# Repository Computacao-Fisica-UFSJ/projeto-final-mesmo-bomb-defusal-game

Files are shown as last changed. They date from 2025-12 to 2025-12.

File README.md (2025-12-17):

# Sistema de Climatização Inteligente via Wi-Fi, com Infravermelho

**Integrantes:**
* Lucas Eduardo Bernardes de Paula
* Messias Feres Curi Melo

## 1. Contextualização do Projeto
Este projeto consiste no desenvolvimento de uma central de automação residencial focada no monitoramento climático e controle de dispositivos via infravermelho (IR). O sistema utiliza um **Arduino Mega** como controlador central, integrando conectividade Wi-Fi para gerenciamento remoto e sensores para leitura ambiental.

O objetivo principal é criar um ecossistema capaz de ler a temperatura e umidade do ambiente e permitir o acionamento remoto de Ar-Condicionados através de uma interface. O projeto explora conceitos de IoT (Internet das Coisas), protocolos de comunicação Serial (UART), manipulação de sinais infravermelhos e servidores Web embarcados.

## 2. Dinâmica e Funcionalidades
O sistema opera executando três tarefas principais simultaneamente:

1. **Monitoramento Climático (DHT22):**
* O sensor lê constantemente a temperatura e a umidade do local.
* Esses dados são exibidos em tempo real na interface Web acessível pelo navegador.

2. **Interface Web e Conectividade (ESP-01):**
* O módulo ESP-01 atua como um servidor Web. Ele gera uma página HTML (estilo "App") que exibe os dados climáticos.

3. **Controle Infravermelho (IR):**
* **Modo de Aprendizado:** O sistema possui um receptor capaz de ler sinais de controles remotos convencionais para "clonar" suas funções.
* **Modo de Envio:** Através de um LED emissor IR, o Arduino replica os códigos salvos para controlar os aparelhos, substituindo o controle físico.

## 3. Lista de Materiais
| Material | Especificação | Quantidade |
| --- | --- | --- |
| **Microcontrolador** | Arduino Mega 2560 | 1 |
| **Módulo Wi-Fi** | ESP8266 (Modelo ESP-01) | 1 |
| **Sensor Climático** | DHT22 (AM2302) | 1 |
| **Receptor IR** | Módulo KY-022 | 1 |
| **Transistor Bipolar** | BC547  | 1 |
| **Emissor IR** | LED Infravermelho (5mm) | 1 |
| **Resistores** | 220Ω e 330Ω (p/ LED) | 2 |
| **Conexões** | Protoboard 400 furos + Jumpers | 1 |

## 4. Diagrama de Montagem
Abaixo está o esquema de ligação dos componentes desenvolvido no software Fritzing.

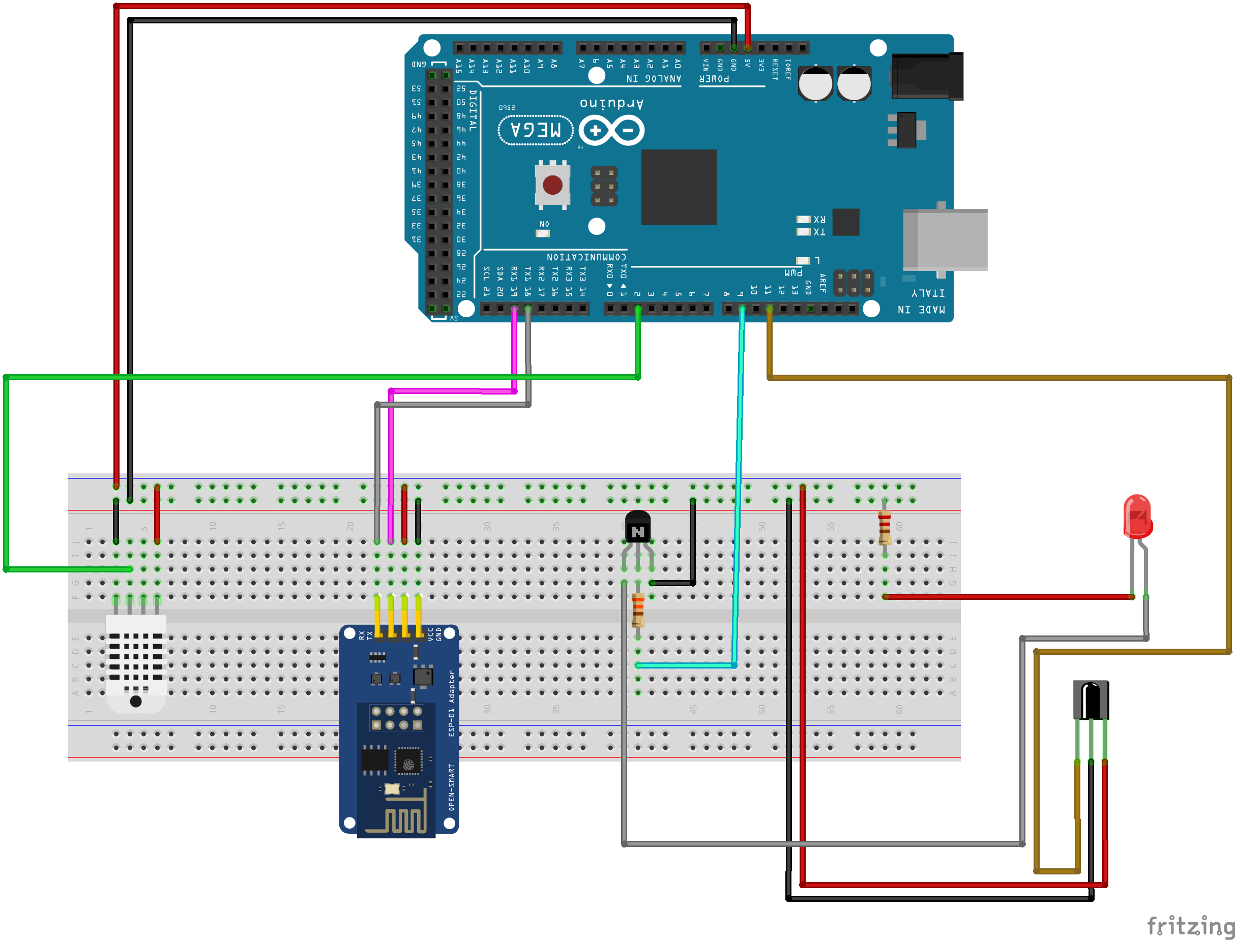
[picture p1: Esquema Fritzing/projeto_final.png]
Arduino Mega
 

## 5. Detalhes da Montagem e Hardware
A escolha do **Arduino Mega 2560** foi estratégica para garantir o desempenho e a estabilidade do sistema, especialmente devido à necessidade de múltiplas portas Seriais de Hardware (HardwareSerial) e o uso de timers específicos exigidos pela biblioteca `IRremote`.

* **Arduino Mega 2560:** Atua como o cérebro do sistema, gerenciando a lógica de controle, leitura de sensores e comunicação com os periféricos. Sua capacidade de memória e número de portas digitais/analógicas facilitam a expansão futura do projeto.
* **ESP-01 (Wi-Fi):** Este módulo é responsável pela conectividade sem fio. Ele está conectado à porta `Serial1` do Arduino Mega (Pinos 18 TX e 19 RX). A utilização da `Serial1` (Hardware Serial) em vez da `SoftwareSerial` (usada no Uno) proporciona uma comunicação muito mais estável, rápida e confiável, essencial para o servidor web.

* **Sensor DHT22:** Conectado ao pino digital `D2`. Este sensor foi escolhido pela sua precisão superior na leitura de temperatura e umidade em comparação ao DHT11, garantindo dados mais confiáveis para o monitoramento ambiental.
* **Receptor IR (KY-022):** Conectado ao pino digital `D11`. Este componente é fundamental para a funcionalidade de "aprendizado" do sistema, permitindo capturar e decodificar os sinais infravermelhos emitidos pelos controles remotos originais dos aparelhos.
* **Emissor IR (LED):** Conectado **obrigatoriamente** ao pino digital `D9`.
* **Nota Técnica Importante:** No Arduino Mega, a biblioteca `IRremote` utiliza especificamente o **Timer 2** do microcontrolador para gerar a frequência portadora de 38kHz necessária para a transmissão do sinal infravermelho. Este timer está fisicamente atrelado ao pino 9, tornando essa conexão mandatória para o funcionamento correto do envio de comandos. Utilizar outro pino resultará na falha da emissão do sinal.

## 6. Interface do Usuário
A interface foi desenvolvida em React VITE, servida diretamente por conexão com o Firebase. Ela permite visualizar a temperatura.

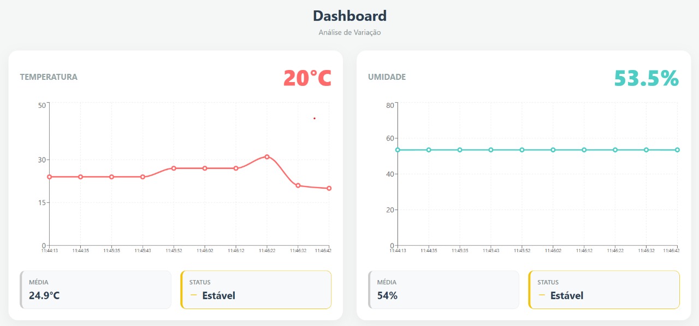
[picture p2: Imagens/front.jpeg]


---

## 7. Foto do Projeto Montado

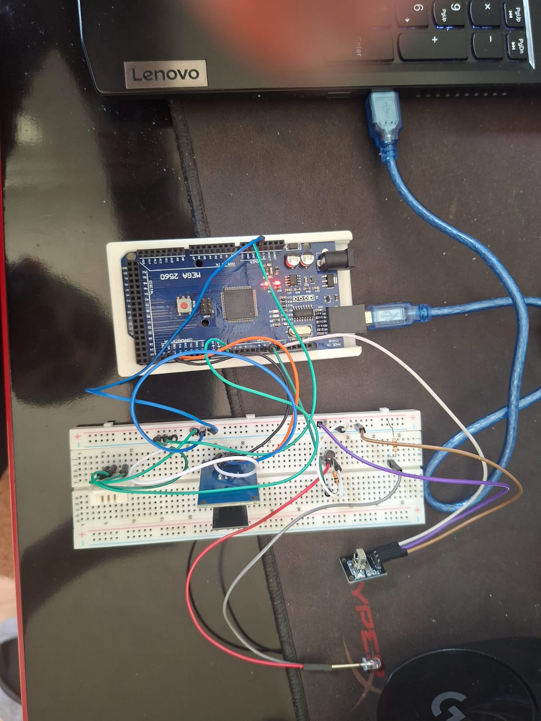
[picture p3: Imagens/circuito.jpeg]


## 8. Demonstração do Projeto (Vídeos)
<span> Também disponíveis na pasta vídeos </span>
<table style="width: 100%; text-align: center;"> 
<tr> <td>
<strong>Clonagem de IR</strong></td> 
<td><strong>Monitoramento de Temperatur </strong></td> 
</tr> <tr> 
<td> <video src="./Vídeos/clonar.mp4" width="350" controls> Seu navegador não suporta o elemento de vídeo. </video> </td> 
<td> <video src="./Vídeos/temperatura.mp4" width="350" controls> Seu navegador não suporta o elemento de vídeo. </video> </td> 
</tr> </table>

## 9. Diário de Bordo 
Abaixo, o registro cronológico das atividades desenvolvidas, organizado por semanas de trabalho:

### **Semana 1: 17/11 a 23/11 — Planejamento e Fundamentos**
**Foco:** Definição do escopo, testes de sensores e conectividade inicial.

* **Planejamento:** Definição do escopo do projeto (Automação de AC via Wi-Fi) e levantamento dos materiais necessários.
* **Sensores:** Estudo do datasheet do Arduino Mega e validação do sensor DHT22 (leitura de temperatura/umidade no Serial Monitor).
* **Conectividade (ESP-01):** Início dos testes com o módulo Wi-Fi. Configuração dos comandos AT.
* **Desafios:** Enfrentamos instabilidade na comunicação com o ESP-01, identificada como problemas na alimentação de 3.3V, exigindo ajustes no circuito.

### **Semana 2: 24/11 a 30/11 — Interface Web e Infravermelho Básico**
**Foco:** Criação do servidor e testes com protocolos simples (TV).

* **Servidor Web:** Desenvolvimento do código HTML embarcado no Arduino. Implementação bem-sucedida da comunicação via `Serial1` (Hardware Serial) do Mega, permitindo acesso ao IP pelo navegador do celular.
* **Infravermelho (Recepção):** Instalação da biblioteca `IRremote` (v4.x) e montagem do receptor KY-022.
* **Sucesso Inicial:** Conseguimos ler, decodificar e replicar códigos de um controle remoto de TV Samsung (Protocolo NEC), validando a lógica de clonagem para sinais curtos.

### **Semana 3: 01/12 a 07/12 — Integração e Estruturação do Código**
**Foco:** Unificação dos módulos e preparação para o Ar-Condicionado.

* **Integração de Sistemas:** Fusão dos códigos do Servidor Web com a lógica de Infravermelho.
* **Refinamento do Hardware:** Organização dos componentes na protoboard para melhorar a estabilidade das conexões.
* **Testes de Envio:** Ajustes no circuito do emissor IR (LED) e testes de alcance com a TV, preparando o terreno para o controle do Ar-Condicionado na semana seguinte.

### **Semana 4: 08/12 a 14/12 — O Desafio do AC e Finalização**
**Foco:** Protocolos complexos, debugging e documentação final.

* **O Problema do AC:** Tentativa de clonar o controle do Ar-Condicionado (Split). O sinal era identificado como `UNKNOWN` ou gerava `OVERFLOW`.
* **Análise Técnica:** Descobrimos que o pacote de dados de um AC é muito maior que o de uma TV, enviando o estado completo (Temperatura, Modo, Fan, Checksum) em um único pulso, o que estourava o buffer padrão da biblioteca.
* **Tentativas de Solução:** Realizamos o aumento do buffer de leitura, análise dos códigos binários "RAW" e troca de resistores para aumentar a potência do LED emissor.
* **Entrega:** Refinamento final da interface Web, montagem final do protótipo para apresentação e redação da documentação técnica relatando as limitações encontradas com o protocolo proprietário do AC.

## 10. Problemas Encontrados e Soluções
Durante o desenvolvimento, o projeto enfrentou desafios técnicos relacionados à eletrônica e ao processamento de sinais. Abaixo, detalhamos os quatro principais obstáculos.

### 1. Complexidade e Tamanho dos Sinais de Ar-Condicionado
Diferente de TVs, que enviam códigos curtos e simples (ex: 32 bits), os controles de ar-condicionado enviam o "estado completo" do aparelho a cada comando, gerando sequências de dados muito longas.

* **O Problema:** A biblioteca de infravermelho frequentemente falhava ao capturar o sinal, interpretando-o como `UNKNOWN`, ou travava o microcontrolador devido ao estouro de memória (buffer overflow).
* **A Causa:** O buffer padrão de recepção não era suficiente para armazenar as centenas de pulsos "RAW" (brutos) necessários para representar um único comando complexo de ar-condicionado.
* **Solução/Desfecho:** Foi necessário aumentar manualmente o tamanho do buffer de recepção (`RAW_BUFFER_LENGTH`) nas configurações da biblioteca e otimizar o código para lidar apenas com arrays de dados brutos, abandonando a tentativa de decodificação hexadecimal para estes aparelhos.

### 2. Instabilidade na Alimentação e Limitações do Hardware
Durante a integração do módulo Wi-Fi ESP-01, o sistema apresentava comportamento errático e falhas de comunicação.

* **O Problema:** O módulo sofria reinicializações aleatórias e desconexões frequentes da rede ao tentar enviar dados, comprometendo a comunicação com o servidor.
* **A Causa:** Identificou-se que o regulador de tensão de 3.3V do **Arduino Uno** não conseguia fornecer a corrente estável necessária para suportar os picos de consumo do ESP-01 durante a transmissão Wi-Fi.
* **Solução/Desfecho:** A solução adotada foi a substituição do microcontrolador: trocou-se o Arduino Uno pelo **Arduino Mega 2560**. O Mega ofereceu maior robustez na alimentação e capacidade de processamento, eliminando as quedas de tensão críticas e estabilizando a conexão do módulo Wi-Fi.

### 3. Conflito de Timers no Hardware (PWM)
Inicialmente, o emissor infravermelho (LED IR) não funcionava, embora o código compilasse sem erros.

* **O Problema:** O LED piscava, mas o sinal não era modulado na frequência correta (38kHz), tornando-o invisível para os receptores dos aparelhos.
* **A Causa:** Restrição de hardware da biblioteca `IRremote`. No Arduino Mega, a modulação de sinal infravermelho é atrelada a timers específicos que obrigam o uso do **Pino 9**. O uso de outros pinos PWM não gera a onda portadora correta.
* **Solução/Desfecho:** A leitura aprofundada da documentação permitiu identificar a restrição e realizar a troca física da conexão para o pino mandatório, resolvendo a emissão do sinal.

### 4. Inviabilidade de Comunicação com Equipamento Elgin
Apesar do sucesso com TVs e receptores de mídia, a integração específica com o ar-condicionado da marca Elgin não foi concluída.

* **O Problema:** O aparelho Elgin ignorava sistematicamente os comandos replicados pelo Arduino, mesmo quando estes pareciam idênticos aos originais sob análise lógica.
* **A Causa:** O protocolo proprietário da Elgin não possui documentação pública e demonstrou uma sensibilidade extrema a variações de microssegundos (*timing jitter*). As pequenas imprecisões temporais naturais da execução do código no Arduino foram suficientes para que o receptor do ar-condicionado rejeitasse o sinal como ruído.
* **Solução/Desfecho:** Em razão das **sucessivas tentativas sem sucesso** na replicação do sinal e da instabilidade persistente na comunicação, a funcionalidade de controle remoto para este modelo de ar-condicionado foi **abandonada** no escopo final do projeto.

## 11. Referências
* **Medição de Temperatura:** [Arduino and DHT22 Temperature Measurement](https://www.instructables.com/Arduino-and-DHT22-AM2302-Temperature-Measurement/)
* **Conectividade Wi-Fi:** [Conectando o Arduino à internet com ESP-01](https://curtocircuito.com.br/blog/IoT/conectando-o-arduino-a-internet-com-esp01)
* **Infravermelho:** [Guia Completo do Controle Remoto IR](https://blog.eletrogate.com/guia-completo-do-controle-remoto-ir-receptor-ir-para-arduino/)
* **Biblioteca Utilizada:** [IRremote by ArminJo](https://github.com/Arduino-IRremote/Arduino-IRremote)

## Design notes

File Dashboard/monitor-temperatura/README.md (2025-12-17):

# Dashboard de Monitoramento de Sensores

Este projeto é uma aplicação front-end desenvolvida em **React** (Vite) para monitoramento em tempo real de dados ambientais (Temperatura e Umidade) provenientes de um **Firebase Realtime Database**.

O sistema exibe gráficos históricos, calcula médias dinâmicas e analisa tendências de variação, além de contar com um sistema de alerta por e-mail para temperaturas críticas.

---

## Tecnologias Utilizadas

- **React.js** (Hooks: `useState`, `useEffect`, `useRef`)
- **Firebase SDK** (Realtime Database)
- **Recharts** (Visualização de dados gráficos)
- **Lucide React** (Ícones dinâmicos)
- **FormSubmit** (API para envio de alertas por e-mail)
- **CSS Modules/Grid** (Layout responsivo)

---

## Fluxo de Exibição de Temperatura

O núcleo da exibição de temperatura ocorre no componente `SensorDashboard.jsx`. Abaixo está o detalhamento de como a informação é processada desde a coleta até a interface:

### 1. Coleta de Dados (Fetching)
A aplicação estabelece um intervalo de atualização a cada **10 segundos** (`setInterval` inside `useEffect`).
- **Fonte:** Nó `sensores/sala` do Firebase Realtime Database.
- **Dados brutos:** O sistema espera receber um objeto contendo `temperatura` e `umidade`.

### 2. Armazenamento e Histórico
Os dados não são apenas sobrescritos, mas acumulados em um array de estado (`historico`):
- O sistema mantém as **últimas 10 leituras** na memória para plotagem do gráfico.
- Cada leitura recebe um *timestamp* local (`hora`) no momento da busca.

### 3. Lógica de Processamento e Análise
A função `processarDados` é executada a cada nova leitura para gerar métricas visuais:

* **Média:** Calcula a média aritmética das leituras presentes no histórico atual.
* **Status de Variação:** Compara a leitura atual com a anterior para definir o status:
    * **Estável:** Variação entre -5°C e +5°C (Cor: Amarelo).
    * **Esquentando Rápido:** Aumento superior a 5°C (Cor: Vermelho).
    * **Resfriando Rápido:** Queda superior a 5°C (Cor: Azul).

### 4. Sistema de Alerta Crítico
Antes de atualizar o estado visual, o sistema verifica se a temperatura excede o limite de segurança:
- **Gatilho:** `temperatura > 35°C`.
- **Ação:** Chama `enviarAlertaEmail`.
- **Debounce:** Utiliza `useRef` para garantir que e-mails só sejam enviados a cada **15 minutos**, evitando spam.

---

## Componentes Visuais (UI)

A interface é dividida em painéis (Cards), onde o painel de Temperatura exibe:

1.  **Valor Atual:** Exibição numérica grande da última leitura.
2.  **Gráfico de Linha (Recharts):**
    * Eixo X: Horário da leitura.
    * Eixo Y: Temperatura (escala automática ou fixa 0-50°C).
    * Linha: Vermelha (`#ff6b6b`) com pontos de marcação.
3.  **Box de Estatísticas:**
    * Exibe a média calculada.
    * Ícone dinâmico (Seta para cima/baixo ou traço) baseado no status de variação.

---

## Configuração do Ambiente

Para rodar o projeto, crie um arquivo `.env` na raiz com as credenciais do Firebase:

```env
VITE_API_KEY=sua_api_key
VITE_AUTH_DOMAIN=seu_projeto.firebaseapp.com
VITE_DATABASE_URL=https://seu_projeto.firebaseio.com
VITE_PROJECT_ID=seu_project_id
VITE_STORAGE_BUCKET=seu_bucket
VITE_MESSAGING_SENDER_ID=seu_id
VITE_APP_ID=seu_app_id

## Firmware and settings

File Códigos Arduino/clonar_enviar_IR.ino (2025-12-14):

#include <DHT.h>
#include <IRremote.hpp>
#include <ctype.h>  

// ===============================================================
// 1. CONFIGURAÇÕES GERAIS
// ===============================================================

const String SSID_REDE  = "DCOMP_UFSJ";
const String SENHA_REDE = "";   

String IP_LOCAL = "";

#define DHTPIN   2
#define DHTTYPE  DHT22
DHT dht(DHTPIN, DHTTYPE);

#define IR_RECEIVE_PIN 11
#define IR_SEND_PIN    9

#define MAX_COMANDOS_IR 10

struct ComandoIR {
  char    nome[16];    
  bool    ativo;        
  uint8_t  protocolo;   
  uint16_t endereco;
  uint16_t comando;
  uint32_t rawData;     
};

ComandoIR listaComandos[MAX_COMANDOS_IR];

decode_type_t ultimoProtocolo = UNKNOWN;
uint16_t      ultimoEndereco  = 0;
uint16_t      ultimoComando   = 0;
uint32_t      ultimoRawData   = 0;
bool          ultimoValido    = false;

// (Opcional) comandos fixos pré-carregados
const ComandoIR COMANDOS_FIXOS[] = {
  // {"LigarTV", true, SAMSUNG, 0x7, 0x2, 0xFD020707}
};
const int NUM_COMANDOS_FIXOS = sizeof(COMANDOS_FIXOS) / sizeof(COMANDOS_FIXOS[0]);

// ===============================================================
// 2. PROTÓTIPOS
// ===============================================================

void handleIRRecepcao();
void salvarNovoComando(const String &nome);
void executarComandoIR(int id);
void deletarComando(int id);
void limparTodosComandos();
void mostrarMenuTerminal();
void verificarTerminal();
void carregarComandosFixos();

float lerTemperatura();
float lerUmidade();

void iniciarWifi();
String lerSerial1(int timeoutMs);
void processarWeb(int idConexao);
void enviarHTML(int idConexao);
void sendCMD(const String &cmd, int waitMs);

// ===============================================================
// 3. SETUP
// ===============================================================
void setup() {
  Serial.begin(9600);     
  Serial1.begin(115200); 

  dht.begin();

  IrReceiver.begin(IR_RECEIVE_PIN, ENABLE_LED_FEEDBACK);
  IrSender.begin(IR_SEND_PIN);

  memset(listaComandos, 0, sizeof(listaComandos));
  ultimoProtocolo = UNKNOWN;
  ultimoEndereco  = 0;
  ultimoComando   = 0;
  ultimoRawData   = 0;
  ultimoValido    = false;

  carregarComandosFixos();

  Serial.println(F("\n========================================"));
  Serial.println(F("   CENTRAL IR + CLIMA (LOCAL APENAS)    "));
  Serial.println(F("========================================"));

  mostrarMenuTerminal();
  iniciarWifi();
}

// ===============================================================
// 4. LOOP
// ===============================================================
void loop() {
  handleIRRecepcao();

  if (Serial1.available()) {
    if (Serial1.find("+IPD,")) {
      delay(30);
      int idConexao = Serial1.read() - '0'; 
      processarWeb(idConexao);
    }
  }

  verificarTerminal();
}

// ===============================================================
// 5. MÓDULO IR - RECEPÇÃO E ARMAZENAMENTO
// ===============================================================
void handleIRRecepcao() {
  if (!IrReceiver.decode()) return;

  IRData &data = IrReceiver.decodedIRData;

  if (data.flags & IRDATA_FLAGS_WAS_OVERFLOW) {
    Serial.println(F("\n[IR] Overflow: sinal muito longo (ignorado)."));
    IrReceiver.resume();
    return;
  }

  if (data.protocol == UNKNOWN &&
      data.address  == 0 &&
      data.command  == 0 &&
      data.decodedRawData == 0) {
    IrReceiver.resume();
    return;
  }

  if (!(data.flags & IRDATA_FLAGS_IS_REPEAT)) {
    ultimoProtocolo = data.protocol;
    ultimoEndereco  = data.address;
    ultimoComando   = data.command;
    ultimoRawData   = data.decodedRawData;
    ultimoValido    = true;

    Serial.println(F("\n--- SINAL IR RECEBIDO ---"));
    Serial.print(F("Protocolo: "));    Serial.println((int)ultimoProtocolo);
    Serial.print(F("Endereco:  0x"));  Serial.println(ultimoEndereco, HEX);
    Serial.print(F("Comando:   0x"));  Serial.println(ultimoComando, HEX);
    Serial.print(F("RawData:   0x"));  Serial.println(ultimoRawData, HEX);
    Serial.println(F("--------------------------"));
    Serial.println(F("Digite 'S' no Serial para salvar este sinal."));
  }

  IrReceiver.resume();
}

void salvarNovoComando(const String &nome) {
  if (!ultimoValido) {
    Serial.println(F("Nenhum sinal valido capturado ainda."));
    return;
  }

  int slot = -1;
  for (int i = 0; i < MAX_COMANDOS_IR; i++) {
    if (!listaComandos[i].ativo) {
      slot = i;
      break;
    }
  }

  if (slot == -1) {
    Serial.println(F("Lista de comandos cheia."));
    return;
  }

  listaComandos[slot].ativo     = true;
  listaComandos[slot].protocolo = (uint8_t)ultimoProtocolo;
  listaComandos[slot].endereco  = ultimoEndereco;
  listaComandos[slot].comando   = ultimoComando;
  listaComandos[slot].rawData   = ultimoRawData;

  nome.toCharArray(listaComandos[slot].nome, sizeof(listaComandos[slot].nome));
  listaComandos[slot].nome[sizeof(listaComandos[slot].nome) - 1] = '\0';

  Serial.print(F("Comando salvo no slot "));
  Serial.println(slot);

  mostrarMenuTerminal();
}

void executarComandoIR(int id) {
  if (id < 0 || id >= MAX_COMANDOS_IR || !listaComandos[id].ativo) {
    Serial.println(F("Slot vazio ou invalido."));
    return;
  }

  ComandoIR &cmd = listaComandos[id];
  decode_type_t proto = (decode_type_t)cmd.protocolo;

  Serial.println(F("\n--- ENVIANDO COMANDO IR ---"));
  Serial.print(F("Slot: "));       Serial.println(id);
  Serial.print(F("Nome: "));       Serial.println(cmd.nome);
  Serial.println(F("--------------------------------"));

  if (proto == UNKNOWN) {
    Serial.println(F("Protocolo UNKNOWN nao suportado."));
    return;
  }

  uint8_t repeats = 2;
  IrSender.write(proto, cmd.endereco, cmd.comando, repeats);

  IrReceiver.enableIRIn();
}

void deletarComando(int id) {
  if (id < 0 || id >= MAX_COMANDOS_IR) return;

  listaComandos[id].ativo     = false;
  listaComandos[id].protocolo = 0;
  listaComandos[id].endereco  = 0;
  listaComandos[id].comando   = 0;
  listaComandos[id].rawData   = 0;
  listaComandos[id].nome[0]   = '\0';

  Serial.print(F("Comando do slot "));
  Serial.print(id);
  Serial.println(F(" apagado."));

  mostrarMenuTerminal();
}

void limparTodosComandos() {
  memset(listaComandos, 0, sizeof(listaComandos));
  Serial.println(F("Todos os comandos foram apagados (RAM)."));
  mostrarMenuTerminal();
}

void carregarComandosFixos() {
  for (int i = 0; i < NUM_COMANDOS_FIXOS && i < MAX_COMANDOS_IR; i++) {
    listaComandos[i] = COMANDOS_FIXOS[i];
  }
}

// ===============================================================
// 6. MENU SERIAL
// ===============================================================
void mostrarMenuTerminal() {
  Serial.println(F("\n===== MENU IR / WEB (LOCAL) ====="));
  Serial.println(F("Slots de comandos IR:"));
  for (int i = 0; i < MAX_COMANDOS_IR; i++) {
    if (listaComandos[i].ativo) {
      Serial.print(F(" ["));
      Serial.print(i);
      Serial.print(F("] "));
      Serial.println(listaComandos[i].nome);
    }
  }

  Serial.println(F("\n[0-9] -> Enviar comando IR do slot"));
  Serial.println(F("[S]   -> Salvar ultimo sinal capturado"));
  Serial.println(F("[D]   -> Deletar comando"));
  Serial.println(F("[C]   -> Limpar TODOS os comandos"));
  Serial.println(F("[T]   -> Mostrar clima atual"));
  Serial.println(F("[L]   -> Listar menu novamente"));
  Serial.println(F("=====================================\n"));
}

void verificarTerminal() {
  if (!Serial.available()) return;

  char c = Serial.read();

  if (c >= '0' && c <= '9') {
    int id = c - '0';
    executarComandoIR(id);
  }
  else if (c == 'S' || c == 's') {
    Serial.println(F("Digite o nome do comando e ENTER:"));
    while (!Serial.available()) {}
    String nome = Serial.readStringUntil('\n');
    nome.trim();
    salvarNovoComando(nome);
  }
  else if (c == 'D' || c == 'd') {
    Serial.println(F("Digite numero do slot a apagar e ENTER:"));
    while (!Serial.available()) {}
    int id = Serial.parseInt();
    deletarComando(id);
  }
  else if (c == 'C' || c == 'c') {
    limparTodosComandos();
  }
  else if (c == 'T' || c == 't') {
    float t = lerTemperatura();
    float h = lerUmidade();
    Serial.print(F("Temp: ")); Serial.print(t);
    Serial.print(F(" C | Umid: ")); Serial.print(h); Serial.println(F("%"));
  }
  else if (c == 'L' || c == 'l') {
    mostrarMenuTerminal();
  }
}

// ===============================================================
// 7. SENSORES (DHT22)
// ===============================================================
float lerTemperatura() {
  float t = dht.readTemperature();
  if (isnan(t)) return NAN;
  return t;
}

float lerUmidade() {
  float h = dht.readHumidity();
  if (isnan(h)) return NAN;
  return h;
}

// ===============================================================
// 8. WIFI + WEB (ESP-01)
// ===============================================================
void iniciarWifi() {
  Serial.println(F("\n[WiFi] Inicializando ESP-01..."));

  sendCMD("AT+RST", 2000);
  sendCMD("AT+CWMODE=1", 1000);

  Serial.print(F("[WiFi] Conectando a: "));
  Serial.println(SSID_REDE);
  
  String cmdJoin = "AT+CWJAP=\"" + SSID_REDE + "\",\"" + SENHA_REDE + "\"";
  sendCMD(cmdJoin, 8000);

  Serial1.println("AT+CIFSR");
  String resp = lerSerial1(2000);

  int ipIndex = resp.indexOf("STAIP,\"");
  if (ipIndex != -1) {
    ipIndex += 7;
    int ipEnd = resp.indexOf('"', ipIndex);
    if (ipEnd != -1) {
      IP_LOCAL = resp.substring(ipIndex, ipEnd);
      Serial.print(F("[WiFi] IP obtido: "));
      Serial.println(IP_LOCAL);
      Serial.print(F("[WiFi] Acesse: http://"));
      Serial.println(IP_LOCAL);
    }
  } else {
    Serial.println(F("[WiFi] IP nao encontrado. Verifique conexao."));
  }

  sendCMD("AT+CIPMUX=1", 1000);
  sendCMD("AT+CIPSERVER=1,80", 1000);
  Serial.println(F("[WiFi] Servidor HTTP pronto."));
}

String lerSerial1(int timeoutMs) {
  String r = "";
  long t0 = millis();
  while (millis() - t0 < timeoutMs) {
    while (Serial1.available()) {
      r += (char)Serial1.read();
    }
  }
  return r;
}

void processarWeb(int idConexao) {
  String req = lerSerial1(300);

  if (req.indexOf("GET /CMD") != -1) {
    int pos = req.indexOf("ID=");
    if (pos != -1) {
      int id = req.substring(pos + 3).toInt();
      executarComandoIR(id);
    }
  }
  else if (req.indexOf("GET /SAVE") != -1) {
    int pos = req.indexOf("N=");
    if (pos != -1) {
      String n = req.substring(pos + 2);
      int espaco = n.indexOf(' ');
      if (espaco != -1) n = n.substring(0, espaco);
      n.trim();
      salvarNovoComando(n);
    }
  }
  else if (req.indexOf("GET /DEL") != -1) {
    int pos = req.indexOf("ID=");
    if (pos != -1) {
      int id = req.substring(pos + 3).toInt();
      deletarComando(id);
    }
  }

  enviarHTML(idConexao);
}

void enviarHTML(int idConexao) {
  float t = lerTemperatura();
  float h = lerUmidade();

  while (Serial1.available()) Serial1.read();

  String html;
  html.reserve(2500);

  html += F("<!DOCTYPE html><html lang='pt-BR'><head>");
  html += F("<meta charset='utf-8'><meta name='viewport' content='width=device-width, initial-scale=1'>");
  html += F("<title>Central IR Local</title>");
  html += F("<style>");
  html += F("body{margin:0;font-family:sans-serif;background:#222;color:#eee;text-align:center;padding:16px;}");
  html += F(".card{background:#333;border-radius:12px;padding:16px;margin:10px auto;max-width:400px;box-shadow:0 4px 10px rgba(0,0,0,0.5);}");
  html += F(".temp{font-size:36px;font-weight:bold;color:#4db8ff;}");
  html += F(".btn{display:block;width:100%;padding:12px;margin:5px 0;background:#009688;color:#fff;text-decoration:none;border-radius:8px;}");
  html += F(".btn-del{background:#d32f2f;width:20%;display:inline-block;margin-left:2%;}");
  html += F(".btn-exec{width:75%;display:inline-block;}");
  html += F("input{width:100%;padding:10px;margin-bottom:8px;border-radius:5px;border:none;}");
  html += F("</style></head><body>");

  html += F("<div class='card'><h2>Central IR (Local)</h2>");
  if (IP_LOCAL.length() > 0) {
    html += F("<small>IP: "); html += IP_LOCAL; html += F("</small><br>");
  }
  html += F("</div>");

  html += F("<div class='card'>");
  html += F("<div class='temp'>");
  if (isnan(t)) html += F("--"); else html += String(t, 1);
  html += F("&deg;C</div>");
  html += F("<div>Umidade: ");
  if (isnan(h)) html += F("--"); else html += String((int)h);
  html += F("%</div></div>");

  html += F("<div class='card'><h3>Controles</h3>");
  bool tem = false;
  for (int i = 0; i < MAX_COMANDOS_IR; i++) {
    if (listaComandos[i].ativo) {
      tem = true;
      html += F("<div>");
      html += "<a class='btn btn-exec' href='/CMD?ID=" + String(i) + "'>" + String(listaComandos[i].nome) + "</a>";
      html += "<a class='btn btn-del' href='/DEL?ID=" + String(i) + "'>X</a>";
      html += F("</div>");
    }
  }
  if (!tem) html += F("<p>Nenhum comando salvo.</p>");
  html += F("</div>");

  html += F("<div class='card'><h3>Novo Comando</h3>");
  if (ultimoValido) {
    html += F("<p style='color:#0f0'>Sinal Capturado!</p>");
    html += F("<input id='nome' placeholder='Nome do comando' />");
    html += F("<a class='btn' href='#' onclick=\"if(nome.value.trim()!=''){location.href='/SAVE?N='+encodeURIComponent(nome.value)}\">Salvar</a>");
  } else {
    html += F("<p>Aponte o controle e aperte um botao...</p>");
    html += F("<a class='btn' style='background:#555' href='/'>Atualizar</a>");
  }
  html += F("</div></body></html>");

  String header = F("HTTP/1.1 200 OK\r\nContent-Type: text/html\r\nConnection: close\r\n\r\n");
  int totalLen = header.length() + html.length();

  String cmd = "AT+CIPSEND=" + String(idConexao) + "," + String(totalLen);
  sendCMD(cmd, 200);

  Serial1.print(header);
  Serial1.print(html);

  delay(200);
  sendCMD("AT+CIPCLOSE=" + String(idConexao), 100);
}

void sendCMD(const String &cmd, int waitMs) {
  Serial1.println(cmd);
  
  Serial.print(F("[ESP] ")); Serial.println(cmd);

  long t0 = millis();
  while (millis() - t0 < waitMs) {
    while (Serial1.available()) {
      Serial1.read(); 
    }
  }
}

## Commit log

2025-12-14 feat: códigos arduino
2025-12-15 feat: fritzing
    [projeto_final.fzz]
2025-12-17 feat: vídeo de demonstração
